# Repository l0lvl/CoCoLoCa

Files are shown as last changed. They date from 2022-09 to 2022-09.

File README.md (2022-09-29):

# CoCoLoCa - MC6847T1 VDG Conversion for CoCo 1 and 2
 
The **CoCoLoCa** allows installation of an MC6847T1/XC80652P in a Radio Shack Colour Computer 1 or 2

This is based on the work of Tony DiStefano as published in the October through December 1986 issues of Rainbow magazine. 

Over the course of two or three articles, Tony explains how to install the new VDG in the Colour Computer, and how to use switches to configure text mode.
This design attempts to cover both the installation and provide jumpers for the text mode settings.

The main PCB (assuming I've interpreted the instructions correctly and failed to make any mistakes) should let you substitute the new MC6847T1/XC80652P VDG in place of the old MC6847. This enables lower case character set (hence the name of this project) as well as a couple of different text mode options. The chip is rather hard to find, but since I have one I thought this would be fun project for #septandy this year.

The main PCB has two fly out lines that have to go to the SAM chip. 

The config plug is installed in place of a 74LS273 that must be removed from the motherboard.  I believe this reconfigures your Coco for some of the data and address pin changes on the new VDG. 

There is an optional SAMTAP board that just lets you easily remove the modification later.

Tony suggests that the wiring for the plug may require a different configuration for CoCo2 models, so expect to see more plugable boards here for those models if that turns out to be the case. I think he also mentioned prizes for sending him the various configuration maps and that he would publish them, but I've come up empty looking for such.

In any case, this design has not been tested so use at your own risk.

Happy #septandy 2022!

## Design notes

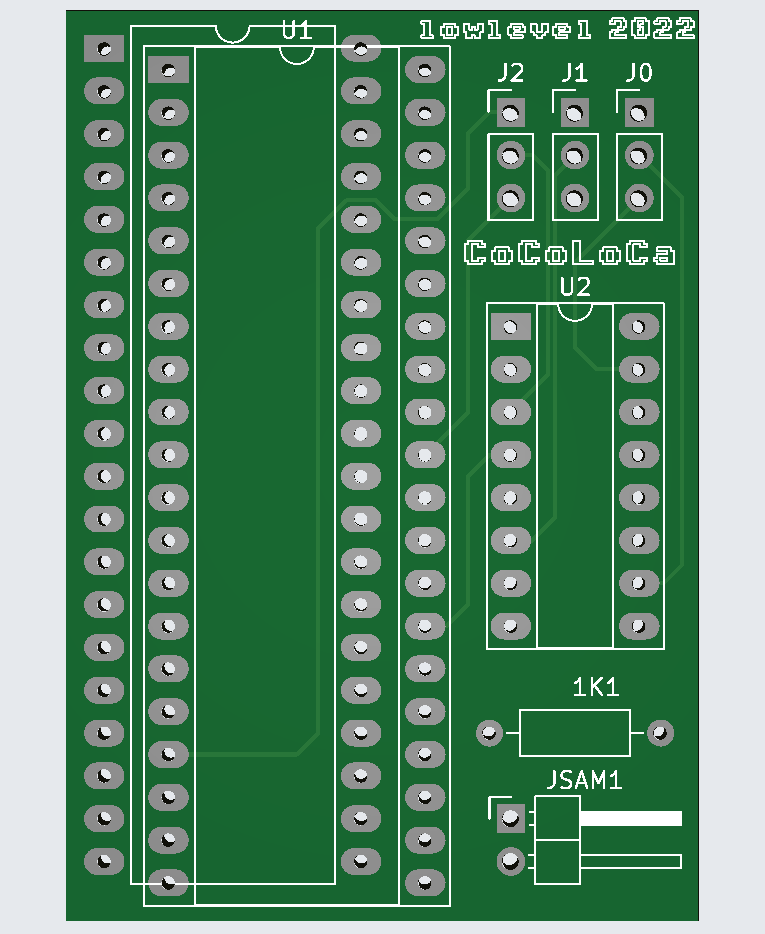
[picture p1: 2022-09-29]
CoCoLoCa.PNG

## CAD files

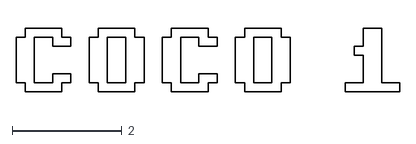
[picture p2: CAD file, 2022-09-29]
Cocoloca-plug-coco/coco1.DXF
7.00 x 1.17

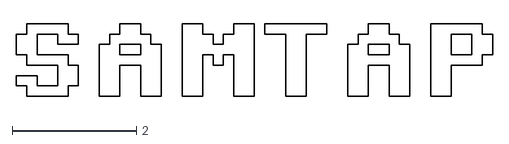
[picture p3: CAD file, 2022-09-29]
Cocoloca-samtap/samtap.DXF
7.66 x 1.17

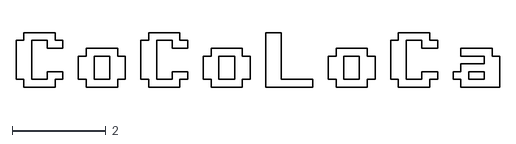
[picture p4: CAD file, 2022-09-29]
cocoloca.DXF
10.3 x 1.17

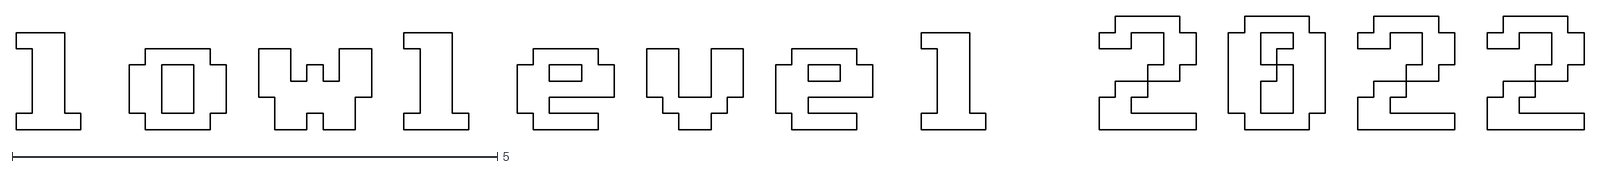
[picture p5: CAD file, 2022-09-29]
lowlevel.DXF
16.2 x 1.17

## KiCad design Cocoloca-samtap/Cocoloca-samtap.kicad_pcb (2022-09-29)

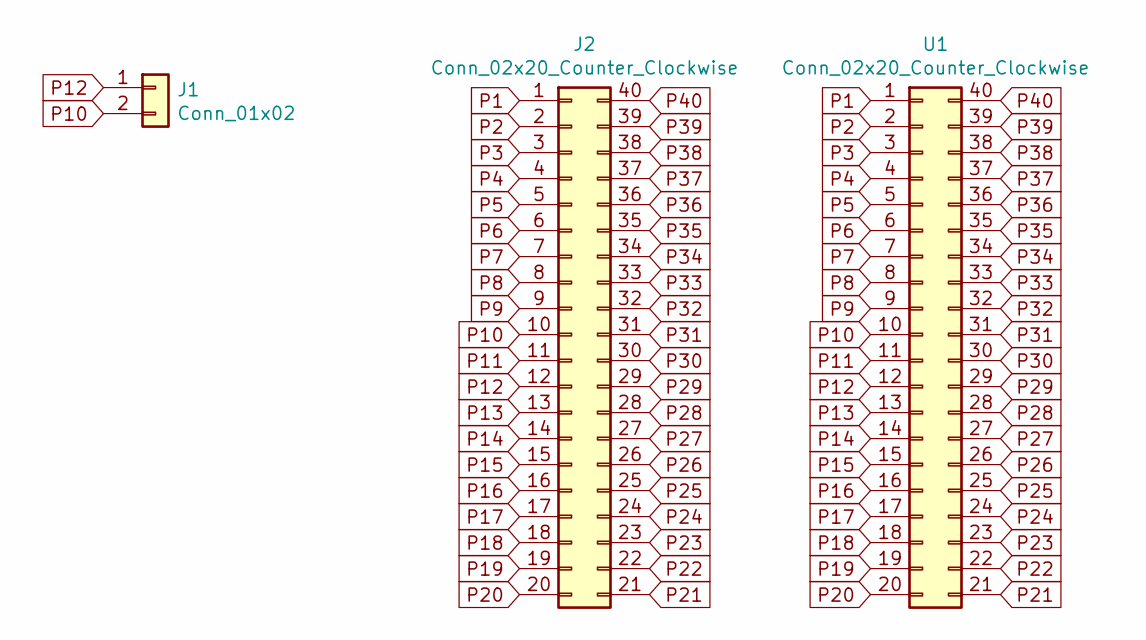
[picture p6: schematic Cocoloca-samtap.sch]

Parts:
J1: Conn_01x02; PinHeader_1x02_P2.54mm_Horizontal
J2: Conn_02x20_Counter_Clockwise; DIP-40_W15.24mm_LongPads
U1: Conn_02x20_Counter_Clockwise; DIP-40_W15.24mm_LongPads

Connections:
P1: J2.1, U1.1
P2: J2.2, U1.2
P3: J2.3, U1.3
P4: J2.4, U1.4
P5: J2.5, U1.5
P6: J2.6, U1.6
P7: J2.7, U1.7
P8: J2.8, U1.8
P9: J2.9, U1.9
P10: J1.2, J2.10, U1.10
P11: J2.11, U1.11
P12: J1.1, J2.12, U1.12
P13: J2.13, U1.13
P14: J2.14, U1.14
P15: J2.15, U1.15
P16: J2.16, U1.16
P17: J2.17, U1.17
P18: J2.18, U1.18
P19: J2.19, U1.19
P20: J2.20, U1.20
P21: J2.21, U1.21
P22: J2.22, U1.22
P23: J2.23, U1.23
P24: J2.24, U1.24
P25: J2.25, U1.25
P26: J2.26, U1.26
P27: J2.27, U1.27
P28: J2.28, U1.28
P29: J2.29, U1.29
P30: J2.30, U1.30
P31: J2.31, U1.31
P32: J2.32, U1.32
P33: J2.33, U1.33
P34: J2.34, U1.34
P35: J2.35, U1.35
P36: J2.36, U1.36
P37: J2.37, U1.37
P38: J2.38, U1.38
P39: J2.39, U1.39
P40: J2.40, U1.40

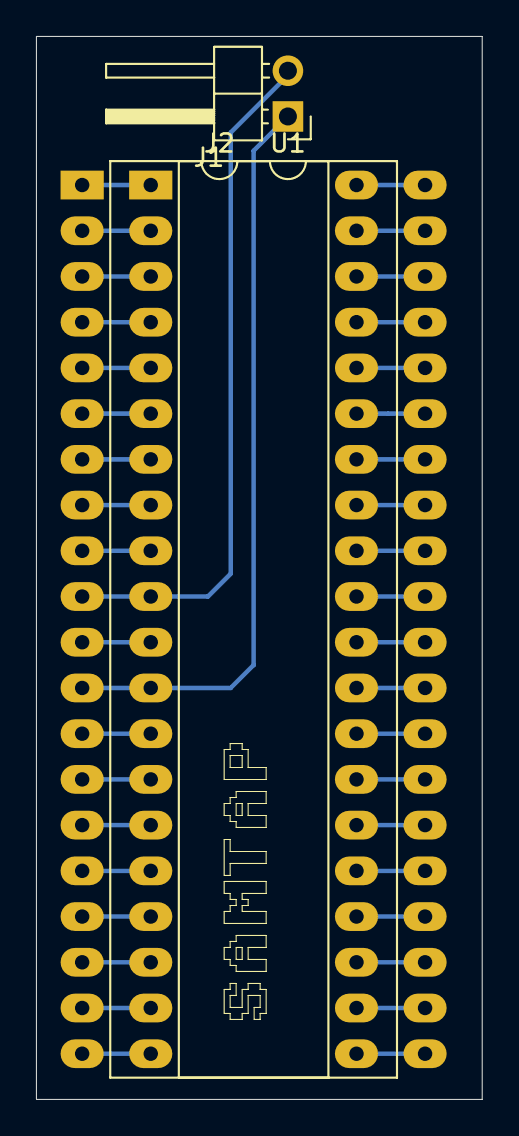
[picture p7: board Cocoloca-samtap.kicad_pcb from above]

Board: 2 copper layers, 24.8 x 59.1 mm, 3 parts (0 on the bottom side), 40 nets.

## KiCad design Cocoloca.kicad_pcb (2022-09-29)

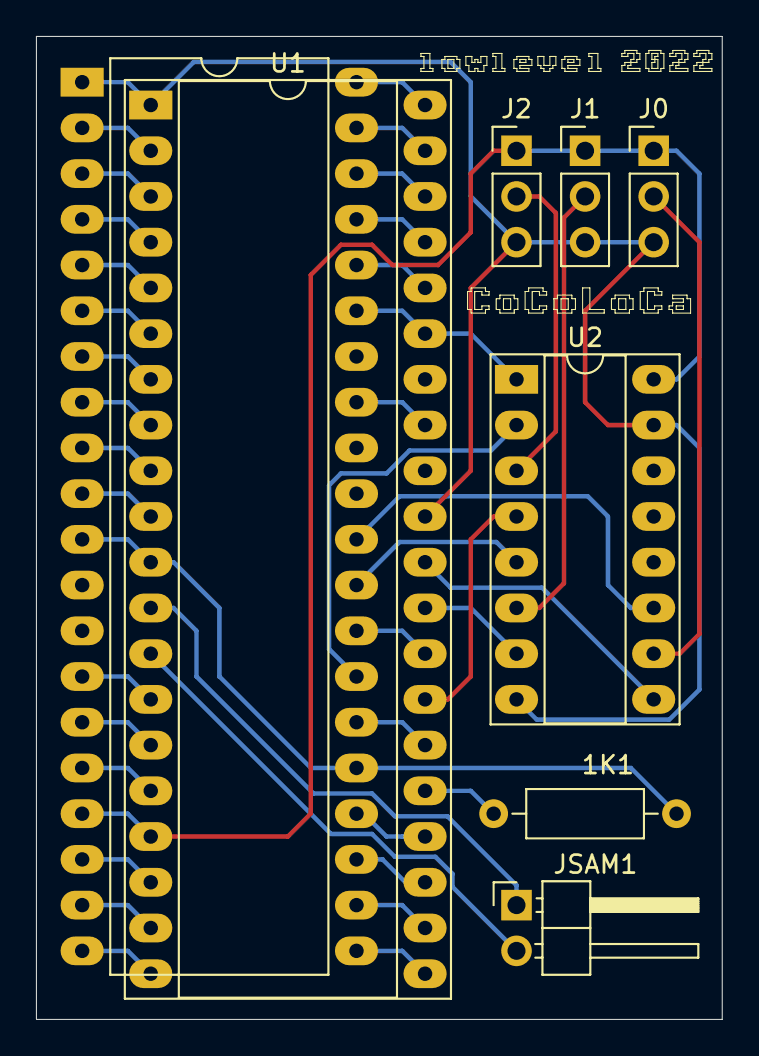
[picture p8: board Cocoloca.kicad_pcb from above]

Board: 2 copper layers, 38.1 x 54.6 mm, 8 parts (0 on the bottom side), 43 nets.

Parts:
1K1: R1; R_Axial_DIN0207_L6.3mm_D2.5mm_P10.16mm_Horizontal
COCOVDG1: MC6847; DIP-40_W15.24mm_LongPads
J0, J1, J2: Conn_01x03_Male; PinHeader_1x03_P2.54mm_Vertical
JSAM1: Conn_01x02_Male; PinHeader_1x02_P2.54mm_Horizontal
U1: MC6847T1; DIP-40_W15.24mm_Socket_LongPads
U2: 74LS157; DIP-16_W7.62mm_Socket_LongPads

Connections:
GND: COCOVDG1.1, J0.3, J1.3, J2.3, U1.1, U1.31, U2.8, U2.15
unnamed: 1K1.1, U1.25
unnamed: COCOVDG1.27, U2.2
unnamed: COCOVDG1.29, U2.5
unnamed: COCOVDG1.30, U2.11
unnamed: U1.27, U2.4
unnamed: U1.29, U2.7
unnamed: U1.30, U2.9
S2: COCOVDG1.2, U1.2
S3: COCOVDG1.3, U1.3
S4: COCOVDG1.4, U1.4
S5: COCOVDG1.5, U1.5
S6: COCOVDG1.6, U1.6
S7: COCOVDG1.7, U1.7
S8: COCOVDG1.8, U1.8
S9: COCOVDG1.9, U1.9
S10: COCOVDG1.10, U1.10
S11: 1K1.2, COCOVDG1.11, COCOVDG1.25, U1.11
S14: COCOVDG1.14, U1.14
S15: COCOVDG1.15, U1.15
S16: COCOVDG1.16, U1.16
S18: COCOVDG1.18, U1.18
S19: COCOVDG1.19, U1.19
S20: COCOVDG1.20, U1.20
S21: COCOVDG1.21, U1.21
S22: COCOVDG1.22, U1.22
S23: COCOVDG1.23, U1.23
S24: COCOVDG1.24, U1.24
S26: COCOVDG1.26, U1.26
S28: COCOVDG1.28, U1.28
S33: COCOVDG1.33, U1.33
S35: COCOVDG1.35, U1.35, U2.1
S36: COCOVDG1.36, U1.36
S37: COCOVDG1.37, U1.37
S38: COCOVDG1.38, U1.38
S39: COCOVDG1.39, U1.39
S40: COCOVDG1.40, U1.40
SAM10: JSAM1.1, U1.12
SAM12: JSAM1.2, U1.13
TGM0: J0.2, U2.10
TGM1: J1.2, U2.6
TGM2: J2.2, U2.3
VCC: COCOVDG1.17, J0.1, J1.1, J2.1, U1.17, U2.16

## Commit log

2022-09-29 Initial check in
    KiCad Schematic and PCB's for MC6847TI Adapter and Config board for 74LS273 socket
    [Cocoloca-B_Cu.gbr, Cocoloca-B_Mask.gbr, Cocoloca-B_Paste.gbr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]
2022-09-29 Gerbers cleaned up
    Added missing edge cuts for Coco1 plug. Added dxf graphic files and cleaned up gerber plots as per board house production specs.
    [Cocoloca-B_Cu.gbl, Cocoloca-B_Mask.gbs, Cocoloca-B_Paste.gbr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]
2022-09-29 Added SAMTAP board
    Optional SAMTAP board to help make the modification easy to reverse. Readme also updated.
    [Cocoloca-samtap-B_Cu.gbl, Cocoloca-samtap-B_Mask.gbs, Cocoloca-samtap-B_SilkS.gbo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]
